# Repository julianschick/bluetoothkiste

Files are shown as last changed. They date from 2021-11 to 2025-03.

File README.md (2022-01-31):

# Bluetoothkiste

Bluetooth-Box für Segelflugzeuge zur Kommunikation zwischen Smartphone (mit beispielsweise XCSoar) und LX (5000/7000/7007) sowie FLARM. LX und FLARM senden über zwei getrennte Bluetooth-Module, werden also als zwei unterschiedliche Serialports auf dem Smartphone sichtbar. Das FLARM wird über den breiten RJ45-Westernstecker an die Box angeschlossen und wird auch über die Box mit Strom versorgt. Das LX wird über die 9-polige D-Sub-Schnittstelle, die meistens mit _PC_ oder _Kolibri_ beschriftet ist, angeschlossen. Eine USB-Buchse kann zusätzlich nach außen gelegt werden, um eine 5V-Stromversorgung im Cockpit zu ermöglichen. Die Datenpins sind nicht angeschlossen.

Die Verbindung zum Flarm kann über Jumper so eingestellt werden, dass keine Daten ans Flarm gesendet werden. Das ist nützlich, wenn man mehrere Bluetooth-Boxen an ein Flarm anschließen will. Die RX- und TX-Leitung zum LX kann per Jumper auf den RS232-Pins 2 und 3 frei konfiguriert werden. Das ist notwendig, da die RX-/TX-Pins vertauscht sind, je nachdem ob man die PC-Schnittstelle (u. U. mit Adapterkabel vom 5-poligen Binderstecker) oder die Kolibri-Schnittstelle verwendet. Im Zweifelsfall durchmessen, auf welchem Pin das Gerät spricht.

Ein Gehäuse, das mit dem 3D-Drucker ausgedruckt werden kann, ist ebenfalls im Repository zu finden. Bilder siehe unten.

## Teileliste

Mit passenden Artikelbezeichnungen für den Berliner Elektroteilehändler [Segor](https://www.segor.de).

Anzahl | Beschreibung | Segor-Artikelbezeichnung
--|--|--
1 | Gehäuse | *PP41 sw*
1 | USB-A-Buchse für Printmontage | *USB-A BU/V*
1 | RJ45-Buchse für Printmontage | *8P8C-BU/S 14mm*
1 | RS232-Converter | *MAX 232 N*
1 | D-Sub Buchse/Stecker 9-polig, Printmontage 90°, Abstand Pinreihe zu Steckerfläche 10mm | *DS09F-90°-10mm*/*DS09M-90°-10mm*
1 | Schaltregler | *R-78 5.0-1.0* oder (günstiger) *R-78E5.0-1.0*
1 | Sicherungshalter für Rundsicherungen, RM 5mm | *RSI-Halter/LP*
1 | Rundsicherung, RM 5mm | *RSI 2,0 A F oder RSI 2,0 A T (flink/träge)*
1 | Schraubklemmen, RM 5mm | *ARK 3 (RM 5mm)*
2 | Kondensator 10u, RM 5mm | *10u-R5.0-X7R/25V*
5 | Kondensator 1u, SMD-Bauform 1206 (3216 metrisch) | *1u0-1206-X7R/50V*
2 | Diode | *1N 5062*
2 | Bluetooth-Modul | *Bluetooth-Modul (HC-05/-06 oder ein HC-10-BLE-Modul)* [günstiger bei eBay!]
div. | Pinheader (je nach Anbringung der Bluetooth-Module)

## Wichtige Hinweise

* Je nachdem, wer zuletzt am Flugzeug rumgefrickelt hat, ist die D-Sub-Verbindung mal Male mal Female, am besten gleich das richtige Gegenstück auf die Platine löten.
* Die Bluetooth-Module können, wenn sie mit vertikalen Pinheader versehen sind, direkt reingesteckt werden (auf der Platine auch vertikale Pinheader anbringen). Sie sind dann vom Gehäusedeckel etwas vorgespannt. Bei eBay bekommt man i.d.R. Module mit 90° abgewinkelten Pinheader, diese kann man aber einfach umbiegen. Man kann sie auch direkt festlöten (ohne Female-Pinheader auf der Platine). Dabei stehen die Stifte nach unten weit aus der Platine heraus. Wenn man diese nicht abzwickt, kann man auch im Nachhinein noch per AT-Kommandos die Bluetooth-Module umkonfigurieren.
* Die Stromversorgung der Bluetooth-Module und des FLARM kann zusammengeschaltet werden per Jumper, wenn man nicht getrennt ein- und ausschalten möchte.
* Das FLARM muss extern abgesichert werden! Intern sind nur die Bluetooth-Module abgesichert.
* Darauf achten, den Schaltregler richtig herum zu montieren. Genauso den RS232-Chip.
* Darauf achten, die Bluetooth-Module richtig herum einzustecken.
* Die Bluetooth-Module müssen vor Benutzung per AT-Kommandos auf die richtige Baudrate eingestellt werden (FLARM meist 19200 und LX meist 4800). Name des Bluetoothgeräts und PIN können auch gesetzt werden. Damit man mit dem LX bidirektional kommunizieren kann, muss die Baudrate der PC-Verbindung des LX auf 4800 gesetzt werden. Das LX wirft seine NMEA-Daten immer mit 4800 Baud aus, kann aber mit konfigurierbarer Baudrate mit dem PC sprechen. Da das alles aber über das gleiche Bluetooth-Modul läuft, sollten 4800 Baud eingestellt sein.

## Bilder

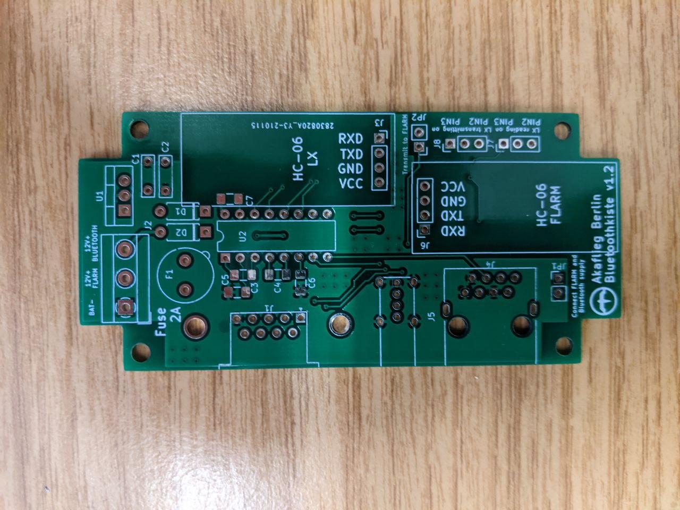
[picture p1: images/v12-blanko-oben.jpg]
Unbestückt oben

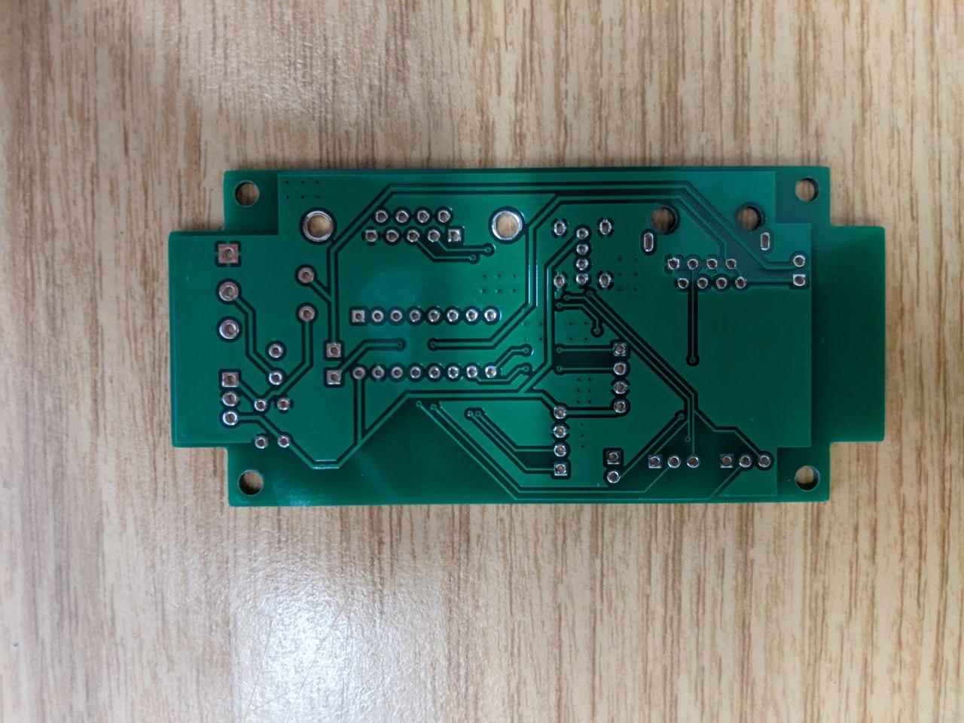
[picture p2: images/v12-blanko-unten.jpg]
Unbestückt unten

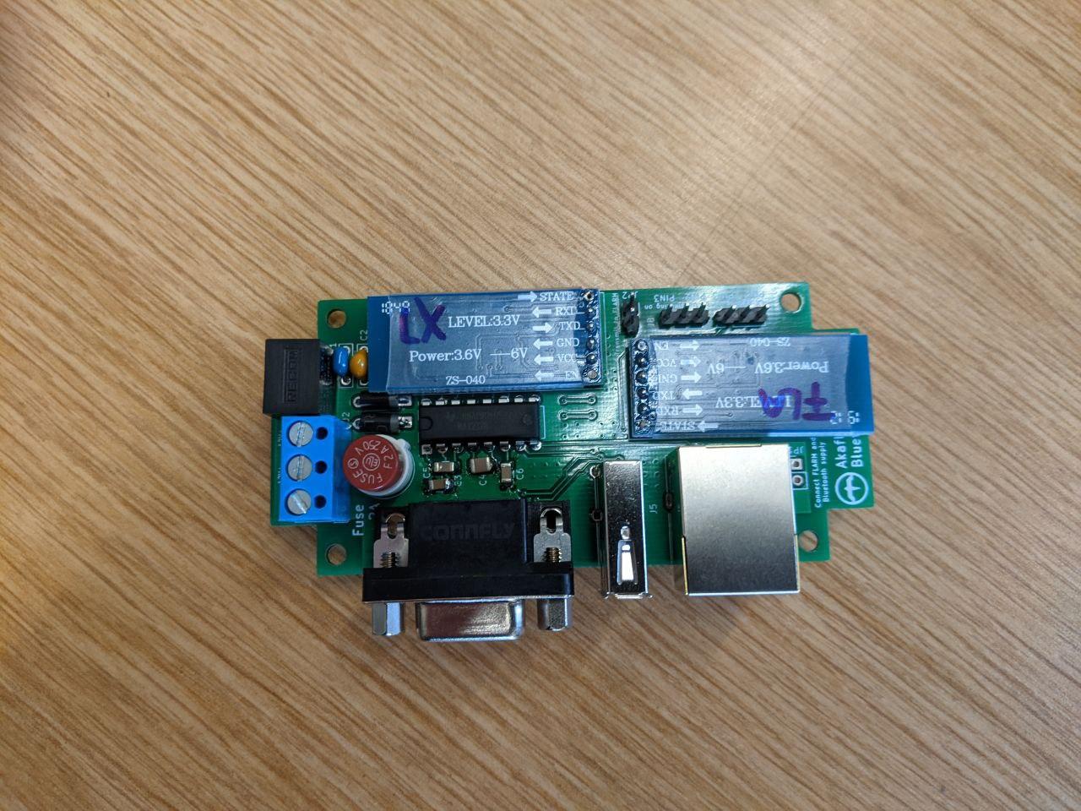
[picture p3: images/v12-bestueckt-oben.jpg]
Bestückt oben

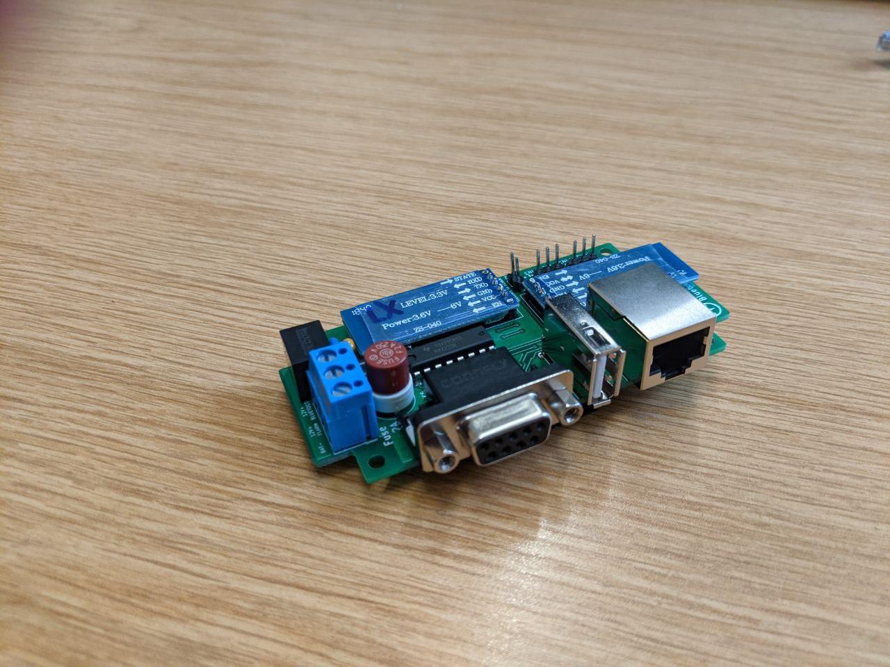
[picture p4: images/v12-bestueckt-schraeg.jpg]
Bestückt schräg

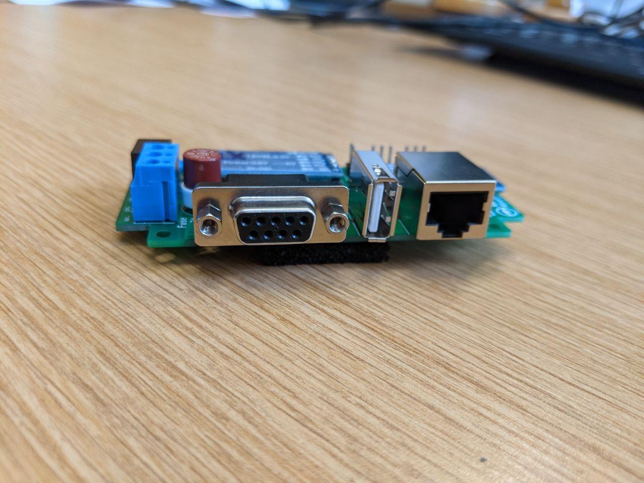
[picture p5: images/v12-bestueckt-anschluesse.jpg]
Bestückt Anschlüsse

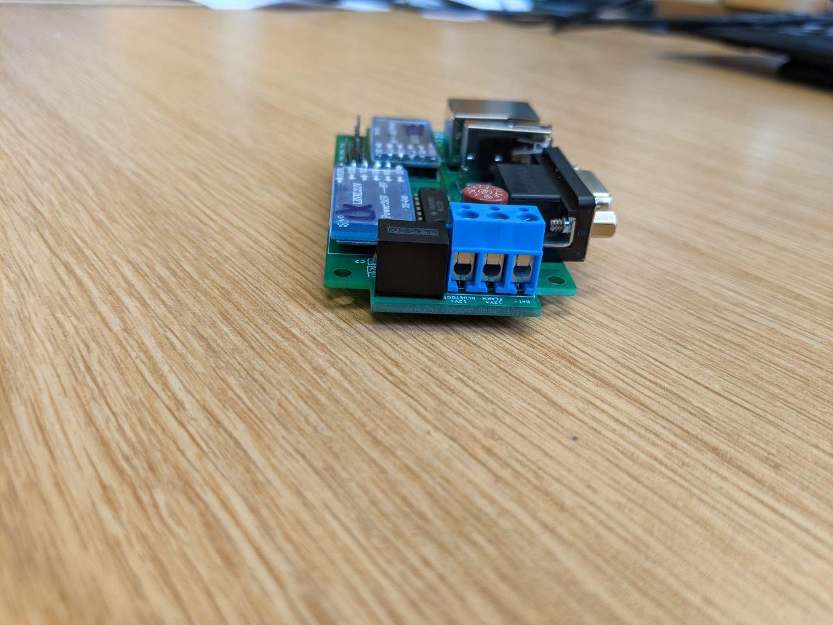
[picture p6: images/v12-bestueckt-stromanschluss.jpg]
Bestückt Stromanschluss

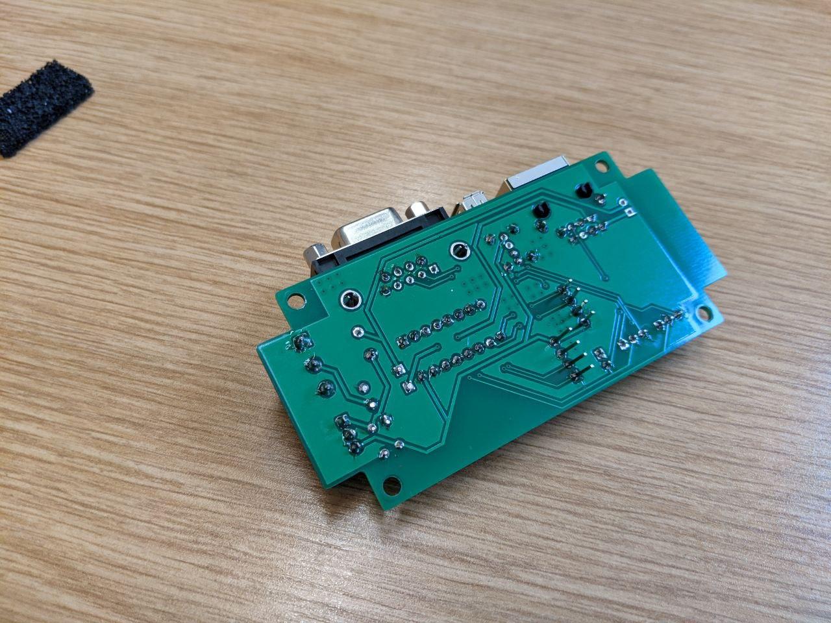
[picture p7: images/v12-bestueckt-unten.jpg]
Bestückt unten


## Gehäuse
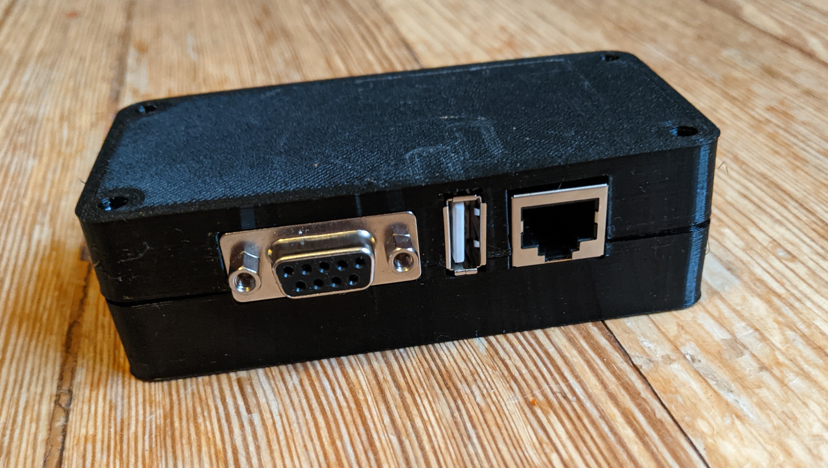
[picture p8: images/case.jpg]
Gehäuse

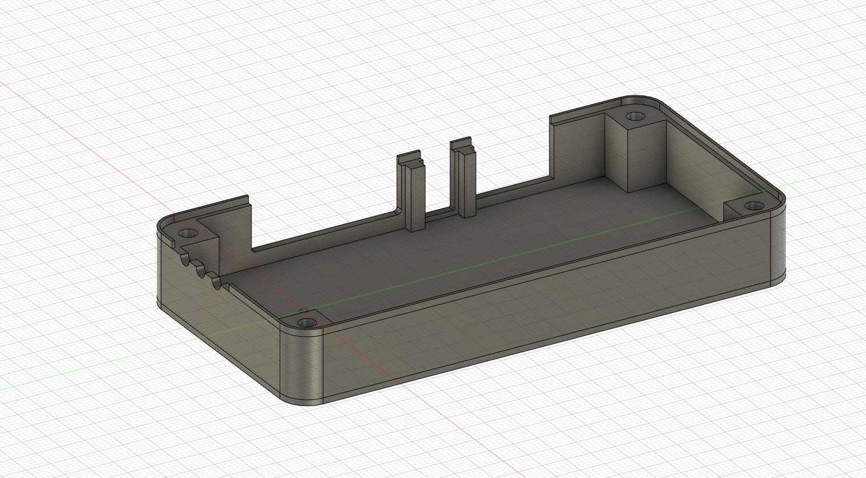
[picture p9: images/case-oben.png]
Oberer Teil des Gehäuses im CAD

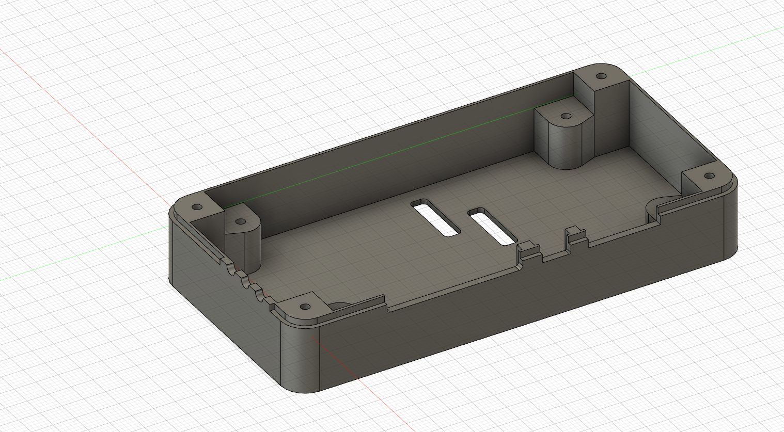
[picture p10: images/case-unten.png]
Unterer Teil des Gehäuses im CAD

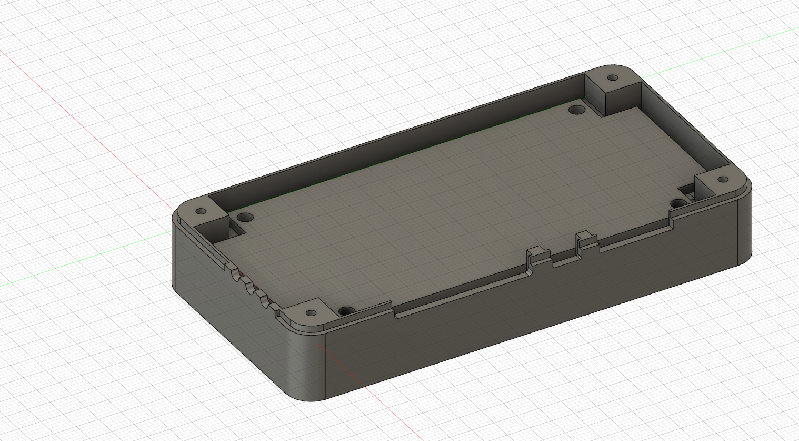
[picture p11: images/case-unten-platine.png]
Unterer Teil des Gehäuses im CAD mit Modell der Platine


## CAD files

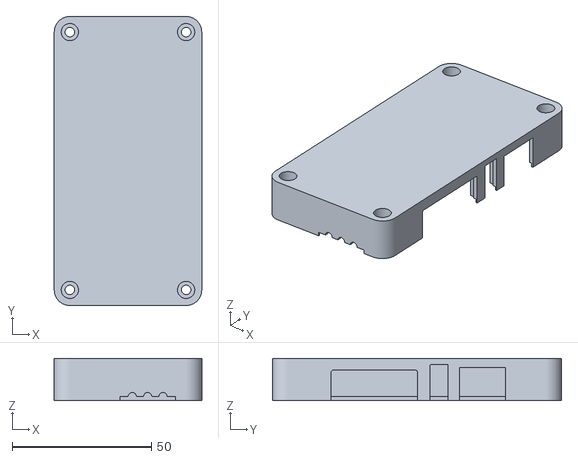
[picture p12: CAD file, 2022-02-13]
case/top.stl
52.9 x 103.6 x 15.1

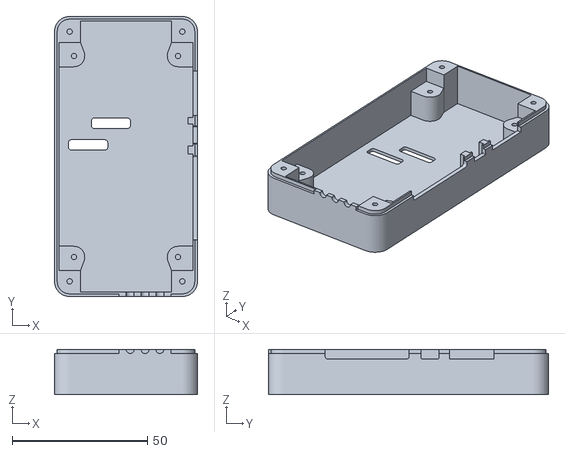
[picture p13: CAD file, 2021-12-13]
case/bottom.stl
52.9 x 103.6 x 16.7

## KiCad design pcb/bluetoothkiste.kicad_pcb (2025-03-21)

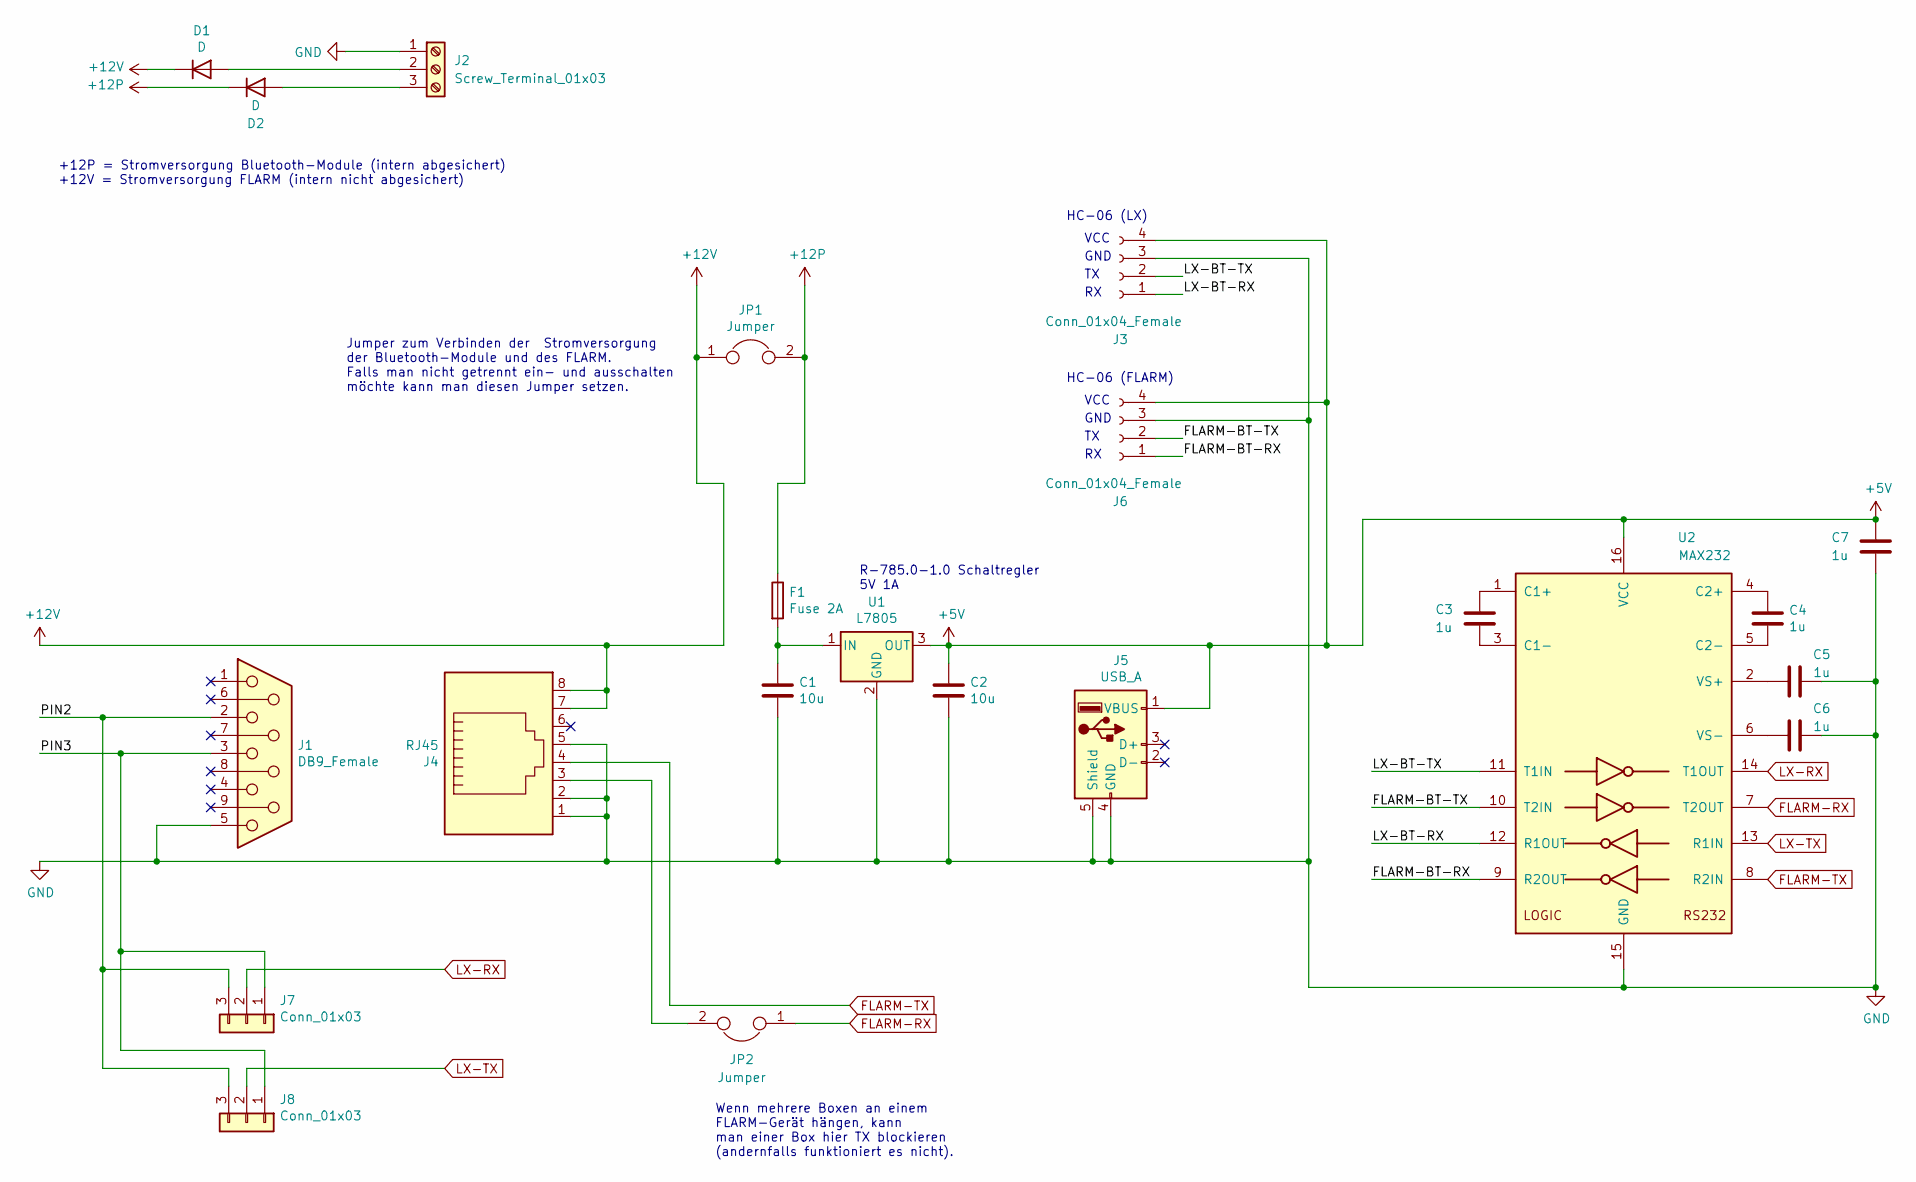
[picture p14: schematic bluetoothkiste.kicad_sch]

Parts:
C1, C2: 10u; C_Rect_L7.0mm_W2.0mm_P5.00mm
C3, C4, C5, C6, C7: 1u; C_1206_3216Metric_Pad1.42x1.75mm_HandSolder
D1, D2: D; D_A-405_P7.62mm_Horizontal
F1: Fuse 2A; Fuseholder_TR5_Littelfuse_No560_No460
J1: DB9_Female; DSUB-9_Female_Horizontal_Pitch2.77x2.54mm_EdgePinOffset9.40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
J2: Screw_Terminal_01x03; TerminalBlock_MetzConnect_Type055_RT01503HDWU_1x03_P5.00mm_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
J3, J6: Conn_01x04_Female; PinSocket_1x04_P2.54mm_Vertical
J4: RJ45; RJ45_SEGOR
J5: USB_A; USB_A_UPRIGHT_SEGOR
J7, J8: Conn_01x03; PinHeader_1x03_P2.54mm_Vertical
JP1, JP2: Jumper; PinHeader_1x02_P2.54mm_Vertical
U1: L7805; TO-220-3_Vertical
U2: MAX232; DIP-16_W7.62mm

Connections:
+5V: C2.1, C7.1, J3.4, J5.1 (VBUS), J6.4, U1.3 (OUT), U2.16 (VCC)
+12P: D2.1 (K), F1.1, JP1.2
+12V: D1.1 (K), J4.7, J4.8, JP1.1
/FLARM-BT-RX: J6.1, U2.9 (R2OUT)
/FLARM-BT-TX: J6.2, U2.10 (T2IN)
/LX-BT-RX: J3.1, U2.12 (R1OUT)
/LX-BT-TX: J3.2, U2.11 (T1IN)
/PIN2: J1.2, J7.3, J8.3
/PIN3: J1.3, J7.1, J8.1
FLARM-RX: JP2.1, U2.7 (T2OUT)
FLARM-TX: J4.4, U2.8 (R2IN)
GND: C1.2, C2.2, C5.1, C6.1, C7.2, J1.5, J2.1, J3.3, J4.1, J4.2, J4.5, J5.4 (GND), J5.5 (Shield), J6.3, U1.2 (GND), U2.15 (GND)
LX-RX: J7.2, U2.14 (T1OUT)
LX-TX: J8.2, U2.13 (R1IN)
unnamed: C1.1, F1.2, U1.1 (IN)
unnamed: C3.1, U2.1 (C1+)
unnamed: C3.2, U2.3 (C1-)
unnamed: C4.1, U2.4 (C2+)
unnamed: C4.2, U2.5 (C2-)
unnamed: C5.2, U2.2 (VS+)
unnamed: C6.2, U2.6 (VS-)
unnamed: D1.2 (A), J2.2
unnamed: D2.2 (A), J2.3
unnamed: J4.3, JP2.2

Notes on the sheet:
GND
HC-06 (LX)
R-785.0-1.0 Schaltregler 5V 1A
VCC
+12P = Stromversorgung Bluetooth-Module (intern abgesichert) +12V = Stromversorgung FLARM (intern nicht abgesichert)
HC-06 (FLARM)
Wenn mehrere Boxen an einem FLARM-Gerät hängen, kann man einer Box hier TX blockieren (andernfalls funktioniert es nicht).
Jumper zum Verbinden der Stromversorgung der Bluetooth-Module und des FLARM. Falls man nicht getrennt ein- und ausschalten möchte kann man diesen Jumper setzen.

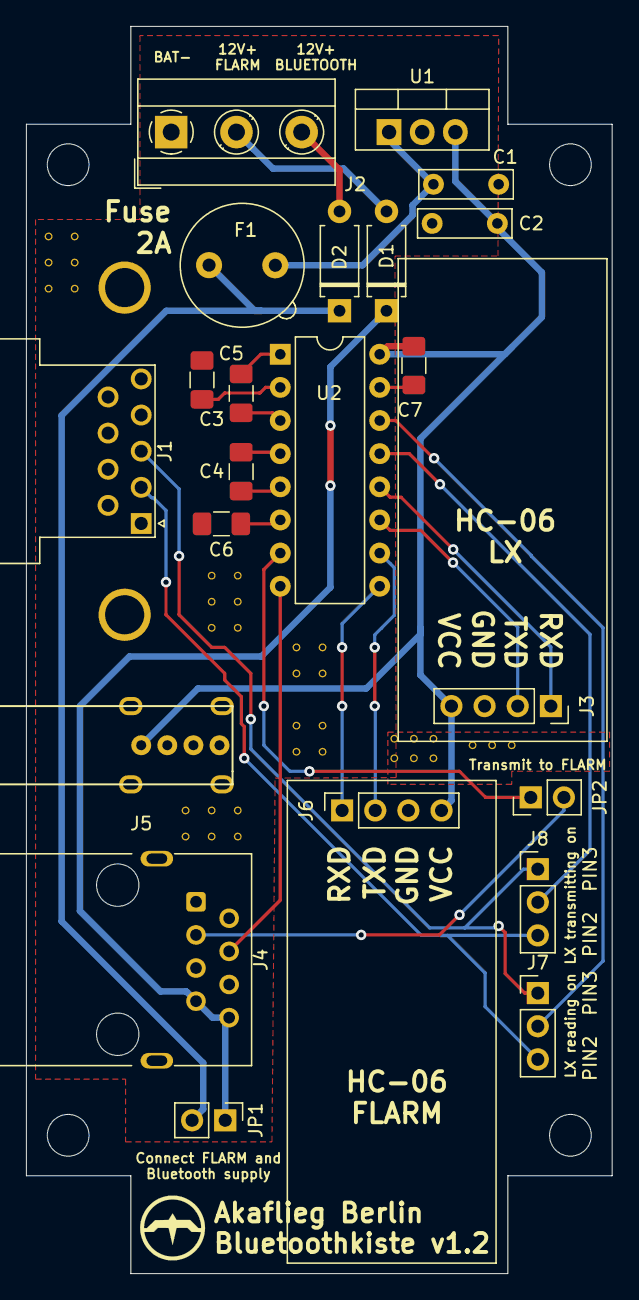
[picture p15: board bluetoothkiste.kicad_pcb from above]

Board: 2 copper layers, 44.9 x 95.6 mm, 22 parts (0 on the bottom side), 24 nets.

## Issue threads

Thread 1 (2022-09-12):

Notwendigkeit des RS232

yorickreum, 2022-09-12:
Ich versuche aktuell eine simplere Version der Bluetooth-Kiste zu bauen, die nur das FLARM mit einem Bluetooth verbindet. Nun habe ich mich gefragt, wozu der RS232 gebraucht wird? Muss hier das serielle Signal umgewandelt werden oder kann RX/TX vom FLARM auch direkt mit einem HC-10 BLE Modul verbunden werden?

Zudem habe ich mich gefragt, ob der RS232 kompatibel mit dem HC-10 ist? Der RS232 gibt ja 5 V TTL Pegel aus, der HC-10 will eigentlich 3.3 V...

Über Hilfestellungen hierzu würde ich mich sehr freuen!

julianschick, 2022-11-13:
Hey,

ich bin so selten hier eingeloggt, vielleicht hilft's dir auch jetzt noch.

Die FLARM-Verbindung arbeitet mit Signalpegel a la RS232 (+12 V/-12 V), also man braucht den Levelshifter von TTL noch. Interessante Nebensache übrigens: Das FLARM liefert auf einer Leitung +3V, mit der man theoretisch die ganze Schaltung betreiben könnte und damit keine extra Stromversorgung bräuchte. Das FLARM *Installation* Manual ist ganz hilfreich (wenn auch nichts, was man als gute Dokumentation beschreiben würde). Achtung die PIN-Nummerierung auf dem Bild des RJ45-Steckers im Manual ist genau gegen Konvention. RJ12 (6-polig) und RJ45 (8-polig) sind bei FLARM generell durch Wiederholung der beiden außenliegenden Pole gewissermaßen kompatibel.

Über diese ganzen HC-xy Bluetoothmodule liest/hört man zwar immer mal wieder, dass sie mit 3.3 V Signalpegel und/oder Betriebsspannung betrieben werden sollen. Aber mir und auch niemandem, den ich kenne, ist jemals einer von denen durchgebrannt bei Betrieb mit 5V auf VCC und den Datenleitungen. Mit den neueren BLE-Modulen habe ich gute Erfahrungen gemacht, die Integration in XCSoar ist einfacher.

Viele Grüße,
Julian

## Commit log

2019-06-02 materialliste korrigiert
2019-06-02 bluetoothkiste -> pcb
    [bluetoothkiste.kicad_pcb, bluetoothkiste.sch]
2019-06-02 beschriftungen pcb
    [bluetoothkiste.kicad_pcb, bluetoothkiste.sch]
2019-06-05 pcb layout
    [bluetoothkiste.kicad_pcb]
2019-06-13 dual channel
    [bluetoothkiste.kicad_pcb, bluetoothkiste.sch]
2019-07-17 bugs in schematic
    [bluetoothkiste.sch]
2019-07-17 layout updated
    [bluetoothkiste.kicad_pcb, bluetoothkiste.sch]
2019-07-30 dioden verpolungsschutz
    [bluetoothkiste.kicad_pcb, bluetoothkiste.sch]
2019-11-06 gerber files
    [bluetoothkiste-B_Cu.GBL, bluetoothkiste-B_Mask.GBS, bluetoothkiste-B_Paste.GBP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]
2020-03-12 footprints updated
    [bluetoothkiste.kicad_pcb, bluetoothkiste.sch]
2021-01-14 gerber v1.2
    [bluetoothkiste-B_Cu.GBL, bluetoothkiste-B_Mask.GBS, bluetoothkiste-B_Paste.GBP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]
2022-01-31 case pic added
2022-01-31 more case pics
2022-02-13 bugfix case top
    [top.stl]
2025-03-21 kicad 9
    [bluetoothkiste.kicad_pcb, bluetoothkiste.kicad_sch]
